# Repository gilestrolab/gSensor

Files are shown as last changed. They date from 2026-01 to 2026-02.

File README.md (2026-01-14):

# gSENSOR

An open-source high-g accelerometer project based on ESP32-C3 and ADXL375.

## Overview

gSENSOR is designed for measuring high-g accelerations (up to ±200g) with real-time display and wireless data streaming. Perfect for impact testing, vibration analysis, and other applications requiring high-g measurement.

## Features

- **High-g Measurement**: ADXL375 accelerometer with ±200g range
- **Real-time Display**: Round LCD showing live X, Y, Z values and magnitude
- **BLE Streaming**: Wireless data transmission at 20Hz to companion app
- **USB Serial Output**: 100Hz CSV data stream for logging
- **Peak Tracking**: Monitor and reset peak acceleration values
- **Android App**: Companion app for visualization, recording, and data export

## Hardware

- **MCU**: ESP32-2424S012 (ESP32-C3 with 1.28" round LCD)
- **Accelerometer**: ADXL375 (±200g, I2C interface)
- **Display**: GC9A01 round LCD (240x240)

### Wiring

| ADXL375 | ESP32-2424S012 |
|---|---|
| VCC | 3.3V |
| GND | GND |
| SDA | GPIO4 |
| SCL | GPIO5 |

## Project Structure

```
gSENSOR/
├── Firmware/           # ESP32 PlatformIO project
│   ├── src/           # Source code
│   ├── include/       # Header files
│   └── platformio.ini # Build configuration
├── gSENSOR-Android/   # Android companion app
│   ├── app/           # App source code
│   └── Dockerfile     # Docker build environment
└── 3D_Printed_Parts/  # Enclosure STL files
```

## Building

### Firmware

```bash
cd Firmware
pio run
pio run -t upload
```

### Android App

Using Docker:
```bash
cd gSENSOR-Android
docker build -t gsensor-android-build .
docker run --rm --user root -e GRADLE_USER_HOME=/tmp/gradle \
  -v "$(pwd):/app" -w /app gsensor-android-build \
  sh -c "./gradlew assembleDebug --no-daemon --project-cache-dir=/tmp/project-cache"
```

APK output: `gSENSOR-Android/app/build/outputs/apk/debug/app-debug.apk`

## BLE Protocol

**Service UUID**: `12345678-1234-5678-1234-56789abcde00`

| Characteristic | UUID | Description |
|---|---|---|
| Accel Data | `...de01` | 20-byte packet: timestamp(4) + x(4) + y(4) + z(4) + magnitude(4) |
| Peak Value | `...de02` | Peak magnitude tracking |
| Control | `...de03` | Commands: 0x01=reset peak, 0x02=reset filters |

## License

MIT License

## Author

**Giorgio Gilestro**
- Email: giorgio@gilest.ro
- GitHub: https://github.com/gilestrolab/gSensor

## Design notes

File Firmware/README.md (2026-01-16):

# gSENSOR Firmware

ESP32-based high-G accelerometer firmware for the ESP32-2424S012 development board with ADXL375 sensor.

## Features

- Real-time acceleration measurement up to **200g**
- Round LCD display with Racing HUD gauge UI
- Configurable sample rates: 100, 200, 400, 800 Hz
- BLE data streaming
- Serial data output (CSV format)
- Touch-based settings interface
- Peak value tracking with visual indicators

## Hardware

### Main Board: ESP32-2424S012

| Component | Specification |
|---|---|
| MCU | ESP32-C3-MINI-1U (4MB Flash) |
| Display | GC9A01 240x240 round LCD |
| Touch | CST816D capacitive |
| Connectivity | WiFi 802.11 b/g/n, Bluetooth 5.0 |
| Power | USB-C or 3.7V LiPo battery |

### Accelerometer: ADXL375

| Parameter | Value |
|---|---|
| Range | +/- 200g |
| Sensitivity | 49 mg/LSB |
| Interface | I2C (0x53) |
| Max Data Rate | 3200 Hz |

### Wiring

Connect the ADXL375 to the JST connector on the ESP32-2424S012:

| ADXL375 | ESP32 GPIO |
|---|---|
| VCC | 3.3V |
| GND | GND |
| SDA | GPIO21 |
| SCL | GPIO20 |

## Building & Flashing

### Prerequisites

- [PlatformIO](https://platformio.org/) (CLI or VSCode extension)

### Build

```bash
cd Firmware
pio run
```

### Flash

```bash
pio run -t upload
```

### Serial Monitor

```bash
pio device monitor
```

## Serial Interface

**Baud Rate:** 115200

### Commands

| Command | Description |
|---|---|
| `r` | Reset peak value |
| `c` | Reset filters (recalibrate) |
| `s1` | Set sample rate to 100 Hz |
| `s2` | Set sample rate to 200 Hz |
| `s3` | Set sample rate to 400 Hz |
| `s4` | Set sample rate to 800 Hz |
| `?` | Show current status |

### Output Format

CSV data is output continuously:

```
timestamp_ms,x,y,z,magnitude,peak
7257,-0.002,-0.375,-0.896,0.972,1.013
7267,-0.012,-0.380,-0.891,0.969,1.013
```

- `timestamp_ms`: Milliseconds since boot
- `x`, `y`, `z`: Acceleration in g (calibrated)
- `magnitude`: Vector magnitude sqrt(x^2 + y^2 + z^2)
- `peak`: Maximum magnitude since last reset

## Serial Plotter Tool

A Python tool for real-time visualization and data recording.

### Installation

```bash
cd tools
pip install -r requirements.txt
```

### Usage

```bash
python serial_plotter.py --port /dev/ttyACM0
```

### Controls

| Key/Button | Action |
|---|---|
| Space | Start/stop recording |
| S | Save recorded data to CSV |
| C | Clear display data |
| R | Reset peak value |

Recording automatically switches to 200 Hz for higher resolution.

## BLE Interface

### Service

- **Device Name:** gSENSOR
- **Service UUID:** `12345678-1234-5678-1234-56789abcde00`

### Characteristics

| Name | UUID | Properties |
|---|---|---|
| Accel Data | `...de01` | Notify |
| Peak | `...de02` | Notify |
| Control | `...de03` | Write |
| Config | `...de04` | Read/Write |

### Control Commands (Write to Control characteristic)

- `0x01` - Reset peak
- `0x02` - Reset filters

### Config (Write to Config characteristic)

- Byte 0: Notification rate in Hz (5-50)

## User Interface

### Main Screen (Racing HUD)

- Arc gauge showing current magnitude
- Digital readout of current value
- Peak value display
- Color-coded thresholds:
  - Green: < 10g
  - Amber: < 50g
  - Coral: < 100g
  - Red: > 100g

### Settings Screen

Tap the display to access settings:

- Toggle BLE on/off
- Toggle Serial output on/off
- Long press to return to main screen

## Configuration

Edit `src/config.h` to customize:

### Sample Rate

```cpp
constexpr uint32_t ADXL_DEFAULT_SAMPLE_RATE_HZ = 100;
```

### Calibration Offsets

Adjust for your specific ADXL375 unit:

```cpp
constexpr float ADXL375_OFFSET_X = 0.35f;
constexpr float ADXL375_OFFSET_Y = -0.60f;
constexpr float ADXL375_OFFSET_Z = 0.70f;
```

### Display Refresh Rate

```cpp
constexpr uint32_t DISPLAY_UPDATE_INTERVAL_MS = 100;  // 10 Hz
```

## Project Structure

```
Firmware/
├── src/
│   ├── main.cpp              # Entry point, main loop
│   ├── config.h              # Hardware config, constants
│   ├── accelerometer.cpp/h   # ADXL375 driver
│   ├── display.cpp/h         # GC9A01 display driver
│   ├── signal_processing.cpp/h  # Filters, magnitude calc
│   ├── ble_service.cpp/h     # BLE GATT server
│   ├── touch.cpp/h           # Touch controller
│   ├── ui_manager.cpp/h      # UI state machine
│   └── settings.h            # Runtime settings
├── tools/
│   ├── serial_plotter.py     # Python visualization tool
│   └── requirements.txt      # Python dependencies
└── platformio.ini            # Build configuration
```

## Dependencies

| Library | Version | Purpose |
|---|---|---|
| LovyanGFX | ^1.1.16 | Display driver |
| Adafruit ADXL375 | ^1.0.1 | Accelerometer driver |
| Adafruit BusIO | ^1.16.1 | I2C abstraction |
| NimBLE-Arduino | ^1.4.0 | BLE stack |

## Troubleshooting

### No serial output

1. Ensure USB CDC is enabled (check `platformio.ini` build flags)
2. Use correct port (`/dev/ttyACM0` on Linux)
3. Check baud rate is 115200

### I2C errors / No accelerometer data

1. Verify wiring to JST connector
2. Check I2C address (default 0x53)
3. Ensure 3.3V power to ADXL375

### Display not working

1. The ESP32-2424S012 uses fixed SPI pins - no configuration needed
2. Check backlight pin (GPIO3) is not conflicting

### Sample rate not changing

1. Ensure firmware is updated (serialEvent fix in v6b3c057)
2. Send command without newline: `s4` not `s4\n`

## License

MIT License - See repository root for details.

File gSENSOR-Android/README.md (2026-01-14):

# gSENSOR Android Companion App

Android companion app for the gSENSOR accelerometer device.

## Features

- **BLE Connection**: Scan and connect to gSENSOR devices via Bluetooth Low Energy
- **Real-time Display**: View live X, Y, Z acceleration and magnitude values
- **Scrolling Chart**: Visual representation of acceleration data over time
- **Peak Tracking**: Monitor and reset peak acceleration values
- **Recording**: Record acceleration sessions to local database
- **CSV Export**: Export recorded sessions to CSV format for analysis
- **Share**: Share exported data via Android share sheet

## Requirements

- Android 8.0 (API 26) or higher
- Bluetooth Low Energy support
- gSENSOR device (ESP32 + ADXL375)

## Building

### Using Docker (recommended)

```bash
docker build -t gsensor-android-build .
docker run --rm --user root -e GRADLE_USER_HOME=/tmp/gradle \
  -v "$(pwd):/app" -w /app gsensor-android-build \
  sh -c "./gradlew assembleDebug --no-daemon --project-cache-dir=/tmp/project-cache && chown -R $(id -u):$(id -g) /app/app/build"
```

The APK will be at `app/build/outputs/apk/debug/app-debug.apk`

### Using Android Studio

1. Open the project in Android Studio
2. Sync Gradle files
3. Build > Build Bundle(s) / APK(s) > Build APK(s)

## Architecture

- **Kotlin** with Jetpack Compose for UI
- **MVVM** architecture pattern
- **Room** database for local storage
- **Coroutines/Flow** for reactive data handling
- **Material3** design components

## Project Structure

```
app/src/main/java/com/gsensor/app/
├── data/
│   ├── ble/          # BLE manager and constants
│   ├── db/           # Room database
│   ├── export/       # CSV export functionality
│   ├── model/        # Data classes
│   └── repository/   # Data repository
├── ui/
│   ├── components/   # Reusable UI components
│   ├── navigation/   # Navigation graph
│   ├── screens/      # App screens
│   └── theme/        # Material theme
└── viewmodel/        # ViewModels
```

## License

MIT License

## Author

Giorgio Gilestro - giorgio@gilest.ro

## Links

- GitHub: https://github.com/gilestrolab/gSensor

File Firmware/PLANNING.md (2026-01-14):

# gSENSOR Firmware - Planning Document

## Project Overview
Firmware for an ESP32-based g-sensor device that records and displays force measurements from a laboratory shaker using an ADXL375 high-g accelerometer.

## Hardware Components

### Main Board: ESP32-2424S012
- **MCU:** ESP32-C3-MINI-1U (4MB Flash)
- **Display:** GC9A01 240x240 round LCD (SPI interface)
- **Touch:** CST816D capacitive touch (unused in this project)
- **Power:** USB-C or 360mAh 3.7V battery
- **Connectivity:** WiFi 802.11 b/g/n, Bluetooth 5.0

### Accelerometer: ADXL375 (Adafruit Breakout)
- **Range:** ±200g (fixed)
- **Sensitivity:** 49 mg/LSB
- **Interface:** I2C (address 0x53)
- **Features:** STEMMA QT/Qwiic connector

## Pin Mapping

### Display (SPI - Fixed on board)
| Function | GPIO |
|---|---|
| MOSI | 7 |
| SCLK | 6 |
| CS | 10 |
| DC | 2 |
| Backlight| 3 |

### ADXL375 I2C (via JST connector)
| JST Pin | GPIO | ADXL375 |
|---|---|---|
| GND | GND  | GND |
| 3.3V | 3.3V | VIN |
| TX | 21 | SDA |
| RX | 20 | SCL |

**Note:** ESP32-C3 only has GPIO0-21. There is no GPIO22!

## Software Architecture

### Framework
- PlatformIO with Arduino framework
- ESP32-C3 target
- LovyanGFX library for display (same as manufacturer's factory firmware)

### Module Structure
```
src/
├── main.cpp              # Application entry point
├── config.h              # Hardware configuration & calibration
├── display.h/.cpp        # GC9A01 display driver (LovyanGFX)
├── accelerometer.h/.cpp  # ADXL375 driver
└── signal_processing.h/.cpp  # Moving average filter
```

### Key Libraries
- LovyanGFX: Display driver (works reliably with ESP32-2424S012)
- Adafruit ADXL375: Accelerometer driver
- Adafruit BusIO: I2C abstraction

## Calibration

The ADXL375 has per-unit zero-g offsets that must be calibrated. Current offsets (measured with sensor flat, screen facing up):

```cpp
OFFSET_X = 0.35f   // X axis offset
OFFSET_Y = -0.60f  // Y axis offset
OFFSET_Z = 0.70f   // Z axis offset (gravity should read 1.0g)
```

To recalibrate:
1. Place sensor flat with screen facing up
2. Read raw X, Y, Z values from serial output
3. X and Y offsets = raw values (should be ~0)
4. Z offset = raw Z value - 1.0 (should be ~1.0g from gravity)

## Design Decisions

### Display Library Choice
- **LovyanGFX** used instead of TFT_eSPI
- Matches manufacturer's factory firmware configuration
- TFT_eSPI had SPI communication issues with this board

### Signal Processing
- Moving average filter with 10-sample window
- Magnitude calculated from raw data before filtering
- Peak tracking with manual reset capability

### Display Update Strategy
- Sample accelerometer at 100 Hz
- Update display at 20 Hz (50ms interval)
- Use sprite buffering to prevent flicker
- Color-coded magnitude (green < 10g, yellow < 50g, orange < 100g, red > 100g)

### I2C Configuration
- Repurpose UART pins (TX/RX) on JST connector as I2C
- GPIO21 = SDA, GPIO20 = SCL
- 400kHz I2C clock

## Serial Interface

**Baud rate:** 115200

**Important:** ESP32-C3 requires USB CDC to be enabled for serial output over USB:
```ini
build_flags =
    -DARDUINO_USB_CDC_ON_BOOT=1
    -DARDUINO_USB_MODE=1
```

**Output format (CSV):**
```
timestamp,x,y,z,magnitude,peak
7257,-0.002,-0.375,-0.896,0.972,1.013
```

**Commands:**
- `r` or `R` - Reset peak value
- `c` or `C` - Reset filters (recalibrate)

**Serial Plotter:**
A Python plotting tool is available in `tools/serial_plotter.py`:
```bash
cd tools
pip install -r requirements.txt
python serial_plotter.py --port /dev/ttyACM0
```

## Future Enhancements
- [ ] Data logging to SPIFFS
- [ ] WiFi data streaming
- [ ] Auto-calibration routine
- [ ] Configurable sample rates
- [ ] FFT analysis for vibration frequency

## References
- [ESP32-2424S012 Info](https://homeding.github.io/boards/esp32c3/jczn-esp32-2424s012.htm)
- [ADXL375 Datasheet](https://www.analog.com/media/en/technical-documentation/data-sheets/ADXL375.PDF)
- [LovyanGFX Library](https://github.com/lovyan03/LovyanGFX)
- [Manufacturer Package](http://pan.jczn1688.com/directlink/1/ESP32%20module/1.28inch_ESP32-2424S012.zip)

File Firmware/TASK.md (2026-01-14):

# gSENSOR Firmware - Task Tracking

## Completed Tasks

### 2026-01-13 - Initial Firmware Development
- [x] Create PlatformIO project structure
- [x] Configure display (switched from TFT_eSPI to LovyanGFX)
- [x] Define hardware pin configuration
- [x] Implement moving average filter
- [x] Implement ADXL375 driver with custom I2C pins
- [x] Implement display module with arc gauge
- [x] Create main application loop
- [x] Fix I2C pins (GPIO20 for SCL, not GPIO22)
- [x] Add sensor calibration offsets
- [x] Create project documentation

## Current Tasks

- [x] Create serial plotter tool

## Backlog

### Software Improvements
- [ ] Add auto-calibration routine on startup
- [ ] Add data logging to SPIFFS
- [ ] Implement WiFi streaming mode
- [ ] Add configurable sample rate via serial command
- [ ] Reduce serial debug output verbosity (add quiet mode)

### UI Enhancements
- [ ] Add min/max hold indicators
- [ ] Implement waveform view mode
- [ ] Add settings screen (touch-based)
- [ ] Improve gauge aesthetics

## Discovered During Work

- ESP32-C3 only has GPIO0-21 (no GPIO22!)
- TFT_eSPI doesn't work reliably with ESP32-2424S012; use LovyanGFX instead
- ADXL375 has significant per-unit zero-g offsets requiring calibration
- Backlight must be enabled AFTER display init (per manufacturer's code)

## Notes

### Wiring Reference
```
ESP32-2424S012 JST     Adafruit ADXL375
-------------------    -----------------
GND  ───────────────── GND
3.3V ───────────────── VIN
TX (GPIO21) ────────── SDA
RX (GPIO20) ────────── SCL
```

Note: ESP32-C3 only has GPIO0-21, there is no GPIO22!

### Calibration Values
Measured with sensor flat, screen facing up:
```cpp
OFFSET_X = 0.35f   // X reads +0.35g, should be 0
OFFSET_Y = -0.60f  // Y reads -0.6g, should be 0
OFFSET_Z = 0.70f   // Z reads +1.7g, should be +1.0g
```

### Serial Commands
- `r` or `R` - Reset peak value
- `c` or `C` - Reset filters (calibrate)

### Debug Output Format
```
RAW: X=0.00 Y=0.00 Z=1.00 | Mag=1.00 | Filtered=1.00 | Peak=1.00
```

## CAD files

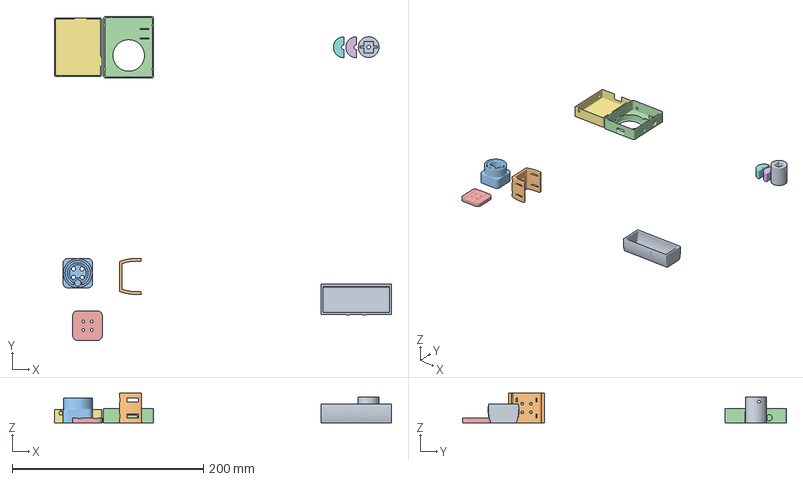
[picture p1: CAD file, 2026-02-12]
3D_Printed_Parts/gSENSOR.3mf
353.0 x 339.2 x 31.0 mm
Shaking sensor - ADXL375.stl
Vortex - Tubes Cradle.stl
Vortex - Round_Adapter.stl
LCD Case - Top.stl
Vortex - ribbon_holder.stl
Shaking sensor - Flug.stl x 2
LCD Case - Bottom.stl
Vortex - Box.stl

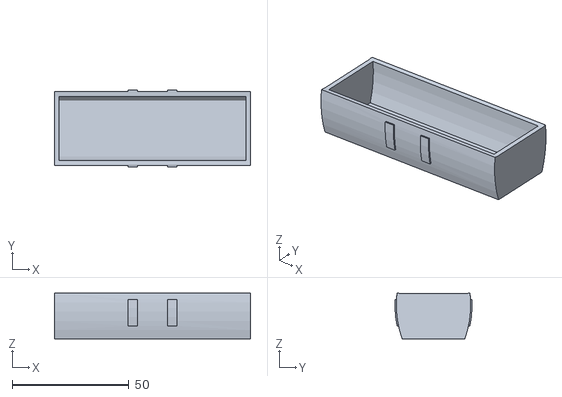
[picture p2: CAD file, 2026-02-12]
3D_Printed_Parts/Vortex/Vortex - Box.stl
84.0 x 33.0 x 19.7

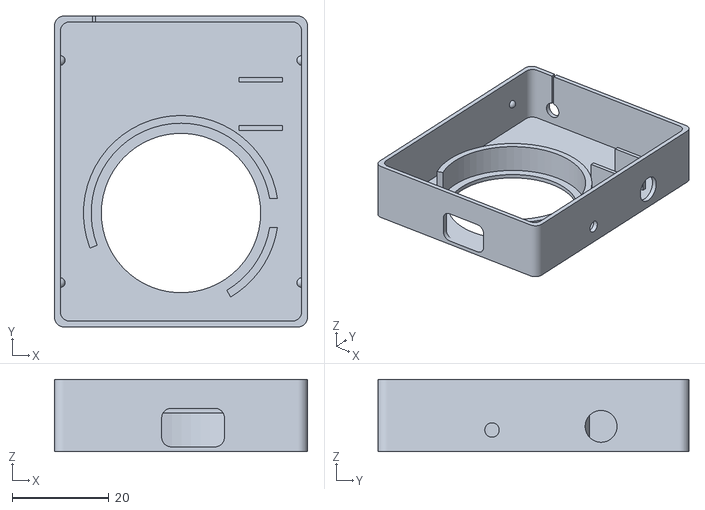
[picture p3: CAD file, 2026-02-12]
3D_Printed_Parts/LCD Case - Top.stl
52.4 x 64.4 x 15.0

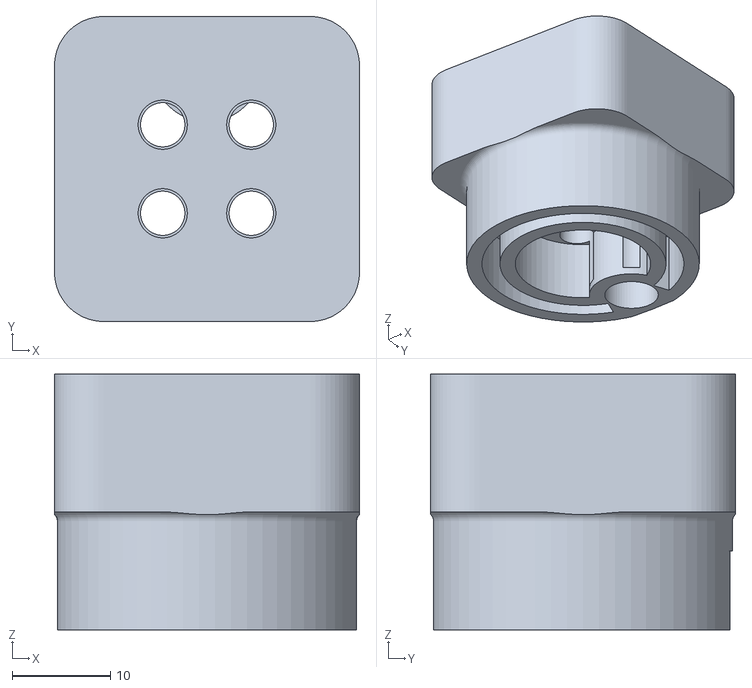
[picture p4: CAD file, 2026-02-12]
3D_Printed_Parts/Vortex/Vortex - Round_Adapter.stl
31.0 x 31.0 x 26.0

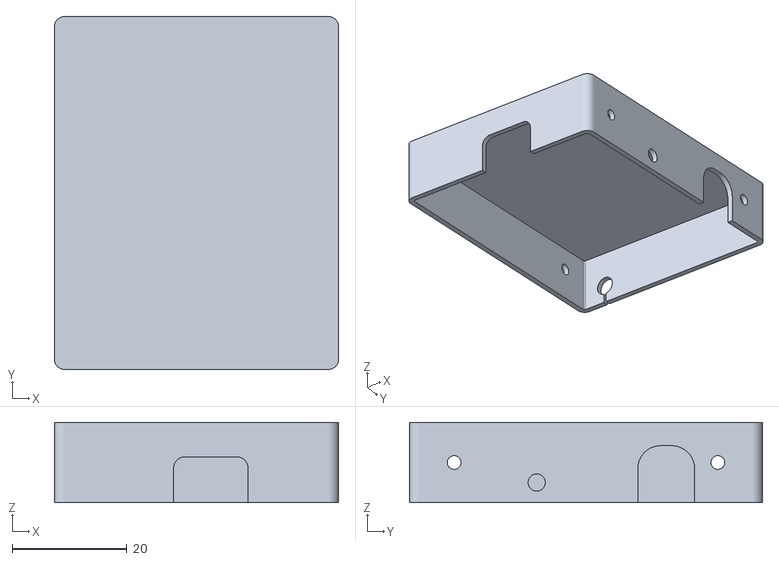
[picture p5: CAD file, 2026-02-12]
3D_Printed_Parts/LCD Case - Bottom.stl
49.6 x 61.6 x 14.0

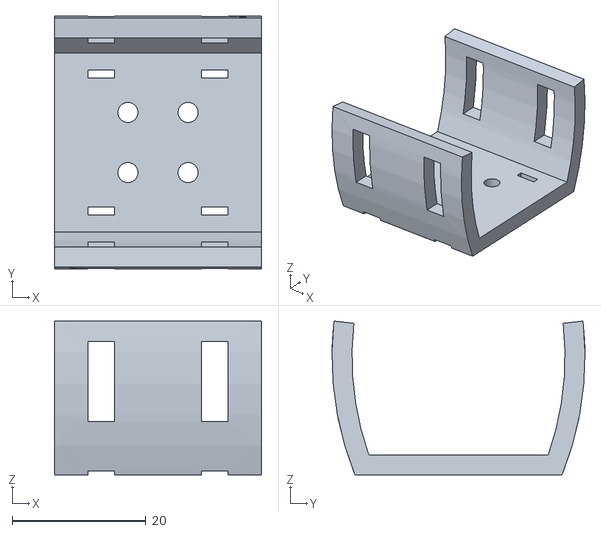
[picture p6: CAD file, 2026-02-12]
3D_Printed_Parts/Vortex/Vortex - Tubes Cradle.stl
31.0 x 37.9 x 23.0

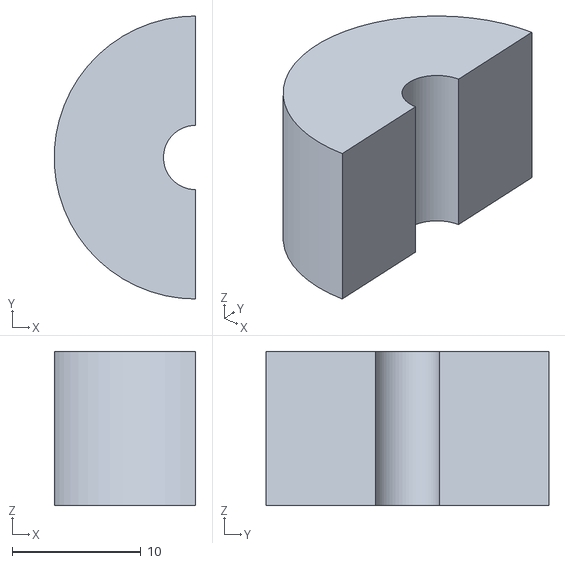
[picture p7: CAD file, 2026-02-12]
3D_Printed_Parts/Shaking sensor - Flug.stl
11.0 x 22.0 x 12.0

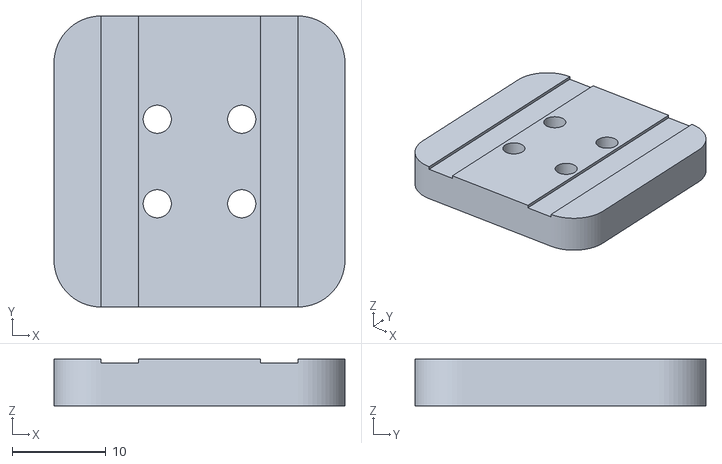
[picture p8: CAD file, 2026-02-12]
3D_Printed_Parts/Vortex/Vortex - ribbon_holder.stl
31.0 x 31.0 x 5.00

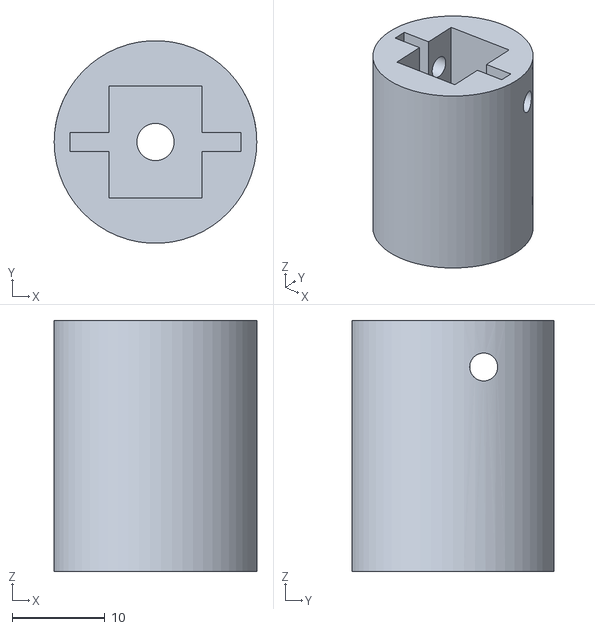
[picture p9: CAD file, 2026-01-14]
3D_Printed_Parts/Shaking sensor - ADXL375.stl
21.8 x 21.8 x 27.0

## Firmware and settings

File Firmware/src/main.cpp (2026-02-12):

/**
 * @file main.cpp
 * @brief gSENSOR main application
 *
 * Real-time g-force display using ESP32-2424S012 board with ADXL375 accelerometer.
 *
 * Hardware:
 *   - ESP32-C3 based ESP32-2424S012 board
 *   - GC9A01 240x240 round LCD display
 *   - ADXL375 high-g accelerometer (±200g) via JST connector
 *
 * Wiring (JST connector to ADXL375):
 *   - GND  -> GND
 *   - 3.3V -> VIN
 *   - TX (GPIO21) -> SDA
 *   - RX (GPIO22) -> SCL
 */

#include <Arduino.h>
#include "config.h"
#include "display.h"
#include "accelerometer.h"
#include "signal_processing.h"
#include "ble_service.h"
#include "touch.h"
#include "settings.h"
#include "ui_manager.h"

// Global objects
Display display;
Accelerometer accel;
SignalProcessor processor;
BleService bleService;
TouchManager touchMgr;
UIManager uiMgr;
Settings settings;

// Hardware timer for precise sampling
hw_timer_t* sampleTimer = nullptr;
volatile bool sampleFlag = false;

// Current sample rate (can be changed at runtime via serial command)
uint32_t currentSampleRateHz = ADXL_DEFAULT_SAMPLE_RATE_HZ;

// Timer ISR - just sets flag, actual I2C read happens in loop
void IRAM_ATTR onSampleTimer() {
    sampleFlag = true;
}

/**
 * @brief Change the accelerometer sample rate at runtime
 *
 * Updates both the hardware timer interval and the ADXL375 data rate register.
 * Valid rates: 100, 200, 400, 800 Hz (limited by serial bandwidth)
 *
 * @param rateHz Target sample rate in Hz
 * @return true if rate was changed successfully
 */
bool setSampleRate(uint32_t rateHz) {
    // Map Hz to ADXL data rate enum
    adxl3xx_dataRate_t adxlRate;
    switch (rateHz) {
        case 100:  adxlRate = ADXL3XX_DATARATE_100_HZ; break;
        case 200:  adxlRate = ADXL3XX_DATARATE_200_HZ; break;
        case 400:  adxlRate = ADXL3XX_DATARATE_400_HZ; break;
        case 800:  adxlRate = ADXL3XX_DATARATE_800_HZ; break;
        default:
            Serial.printf("Invalid rate: %d Hz\n", rateHz);
            return false;
    }

    // Update ADXL375 data rate
    accel.setDataRate(adxlRate);

    // Calculate new timer interval in microseconds
    uint32_t intervalUs = 1000000 / rateHz;

    // Update hardware timer
    timerAlarmDisable(sampleTimer);
    timerAlarmWrite(sampleTimer, intervalUs, true);
    timerAlarmEnable(sampleTimer);

    currentSampleRateHz = rateHz;
    Serial.printf("Sample rate: %d Hz\n", rateHz);
    return true;
}

// Timing variables
uint32_t lastDisplayTime = 0;
uint32_t lastBLENotifyTime = 0;

// State
bool sensorOk = false;

// Forward declaration (ESP32 doesn't auto-call serialEvent like classic Arduino)
void serialEvent();

/**
 * @brief Arduino setup function
 */
void setup() {
    // Initialize serial for debugging
    Serial.begin(SERIAL_BAUD_RATE);
    delay(500);  // Give serial more time to initialize

    Serial.println();
    Serial.println("================================");
    Serial.println("  gSENSOR - High-G Accelerometer");
    Serial.println("================================");
    Serial.println();
    Serial.println("[Setup] Starting...");

    // Initialize display first (shows splash screen)
    Serial.println("[Setup] Initializing display...");
    if (!display.begin()) {
        Serial.println("ERROR: Display initialization failed!");
        while (1) {
            delay(500);
        }
    }
    Serial.println("[Setup] Display OK, showing splash...");

    display.showSplash();
    Serial.println("[Setup] Splash shown, waiting...");
    delay(1500);  // Show splash for 1.5 seconds

    // Initialize accelerometer
    Serial.println("[Setup] Initializing ADXL375...");
    sensorOk = accel.begin();

    if (!sensorOk) {
        display.showError("ADXL375 NOT FOUND");
        Serial.println("ERROR: Accelerometer initialization failed!");
        Serial.println("Check wiring:");
        Serial.println("  JST GND  -> ADXL375 GND");
        Serial.println("  JST 3.3V -> ADXL375 VIN");
        Serial.println("  JST TX   -> ADXL375 SDA");
        Serial.println("  JST RX   -> ADXL375 SCL");
        // Continue anyway to show error on display
    } else {
        Serial.println("[Setup] ADXL375 OK, drawing UI...");
        // Clear display and draw static UI
        display.clear();
        display.drawStaticUI();
        Serial.println("[Setup] UI drawn");
    }

    // Initialize touch controller
    Serial.println("[Setup] Initializing touch...");
    if (touchMgr.begin()) {
        Serial.println("[Setup] Touch controller OK");
    } else {
        Serial.println("WARNING: Touch controller not found");
    }

    // Initialize BLE
    Serial.println("[Setup] Initializing BLE...");
    bleService.begin();
    Serial.println("[Setup] BLE OK");

    // Register BLE command callback
    bleService.setCommandCallback([](uint8_t cmd) {
        switch (cmd) {
            case BLE_CMD_RESET_PEAK:
                processor.resetPeak();
                display.resetGaugeMax();
                if (DEBUG_ENABLED) {
                    Serial.println("BLE: Peak reset");
                }
                break;

            case BLE_CMD_RESET_FILTERS:
                processor.reset();
                if (DEBUG_ENABLED) {
                    Serial.println("BLE: Filters reset");
                }
                break;

            case BLE_CMD_SET_SAMPLE_RATE_100HZ:
                if (setSampleRate(ADXL_RATE_100HZ)) {
                    settings.sampleRateHz = ADXL_RATE_100HZ;
                    if (DEBUG_ENABLED) {
                        Serial.println("BLE: Sample rate set to 100 Hz");
                    }
                }
                break;

            case BLE_CMD_SET_SAMPLE_RATE_200HZ:
                if (setSampleRate(ADXL_RATE_200HZ)) {
                    settings.sampleRateHz = ADXL_RATE_200HZ;
                    if (DEBUG_ENABLED) {
                        Serial.println("BLE: Sample rate set to 200 Hz");
                    }
                }
                break;

            case BLE_CMD_SET_SAMPLE_RATE_400HZ:
                if (setSampleRate(ADXL_RATE_400HZ)) {
                    settings.sampleRateHz = ADXL_RATE_400HZ;
                    if (DEBUG_ENABLED) {
                        Serial.println("BLE: Sample rate set to 400 Hz");
                    }
                }
                break;

            default:
                if (DEBUG_ENABLED) {
                    Serial.print("BLE: Unknown command 0x");
                    Serial.println(cmd, HEX);
                }
                break;
        }
    });

    // Initialize physical button
    pinMode(PIN_BUTTON, INPUT_PULLUP);
    Serial.println("[Setup] Button initialized on GPIO9");

    // Set up hardware timer for sampling
    // Timer 0, prescaler 80 (80MHz/80 = 1MHz tick rate), count up
    sampleTimer = timerBegin(0, 80, true);
    timerAttachInterrupt(sampleTimer, &onSampleTimer, true);
    // Set initial rate (can be changed at runtime via serial command s1-s4)
    uint32_t initialIntervalUs = 1000000 / ADXL_DEFAULT_SAMPLE_RATE_HZ;
    timerAlarmWrite(sampleTimer, initialIntervalUs, true);
    timerAlarmEnable(sampleTimer);
    Serial.printf("[Setup] Sample timer configured for %d Hz (s1-s4 to change)\n", ADXL_DEFAULT_SAMPLE_RATE_HZ);

    // Initialize timing
    lastDisplayTime = millis();
    lastBLENotifyTime = millis();

    Serial.println("[Setup] Complete! Entering main loop...");
}

/**
 * @brief Arduino main loop
 */
void loop() {
    // Sample accelerometer FIRST when timer fires (highest priority!)
    // The timer ISR sets sampleFlag at precise 100Hz intervals
    if (sampleFlag && sensorOk) {
        sampleFlag = false;  // Clear flag immediately

        AccelData raw;
        if (accel.read(raw)) {
            // Process through moving average filter
            AccelData filtered = processor.process(raw);

            // Serial output in CSV format for plotting (if enabled)
            // Format: timestamp,x,y,z,magnitude,peak
            if (DEBUG_ENABLED && settings.serialEnabled) {
                float mag = processor.getFilteredMagnitude();
                float peak = processor.getPeakMagnitude();

                Serial.print(millis());
                Serial.print(",");
                Serial.print(filtered.x, 3);
                Serial.print(",");
                Serial.print(filtered.y, 3);
                Serial.print(",");
                Serial.print(filtered.z, 3);
                Serial.print(",");
                Serial.print(mag, 3);
                Serial.print(",");
                Serial.println(peak, 3);
            }
        }
    }

    uint32_t now = millis();

    // Handle physical button (active LOW, debounced)
    static bool lastButtonState = HIGH;
    static uint32_t lastButtonTime = 0;
    bool buttonState = digitalRead(PIN_BUTTON);

    if (buttonState != lastButtonState && (now - lastButtonTime) > 200) {
        lastButtonTime = now;
        if (buttonState == LOW) {
            // Button pressed - toggle screen
            if (uiMgr.getScreen() == UIScreen::MAIN_GAUGE) {
                uiMgr.setScreen(UIScreen::SETTINGS);
                Serial.println("[Button] Opening settings");
            } else {
                uiMgr.setScreen(UIScreen::MAIN_GAUGE);
                Serial.println("[Button] Back to gauge");
            }
        }
        lastButtonState = buttonState;
    }

    // Handle touch input (skipped if no touch controller)
    touchMgr.update();
    TouchEvent event = touchMgr.getEvent();
    if (event.gesture != TouchGesture::NONE) {
        uiMgr.handleTouch(event, settings);

        // Handle BLE enable/disable from settings
        bleService.setEnabled(settings.bleEnabled);
    }

    // Handle peak reset from UI (long press)
    if (uiMgr.peakResetRequested()) {
        processor.resetPeak();
        display.resetGaugeMax();
        if (DEBUG_ENABLED && settings.serialEnabled) {
            Serial.println("Peak reset (touch)");
        }
    }

    // Update display at lower rate (to prevent flicker and save CPU)
    if (now - lastDisplayTime >= DISPLAY_UPDATE_INTERVAL_MS) {
        lastDisplayTime = now;

        // Check if screen changed (need to prepare)
        if (uiMgr.screenChanged()) {
            display.prepareScreen();
        }

        // Draw appropriate screen
        if (uiMgr.getScreen() == UIScreen::MAIN_GAUGE) {
            AccelData accelData = {0, 0, 0};
            float magnitude = 0.0f;
            float peak = 0.0f;

            if (sensorOk) {
                accelData = processor.getLastFiltered();
                magnitude = processor.getFilteredMagnitude();
                peak = processor.getPeakMagnitude();
            }

            display.update(accelData, magnitude, peak);
        } else {
            // Settings screen
            display.drawSettingsScreen(settings, bleService.isConnected());
        }
    }

    // Send BLE notifications at configured rate (if BLE is enabled)
    if (settings.bleEnabled && bleService.isConnected() && sensorOk) {
        uint32_t bleInterval = 1000 / bleService.getNotificationRate();
        if (now - lastBLENotifyTime >= bleInterval) {
            lastBLENotifyTime = now;

            const AccelData& filtered = processor.getLastFiltered();
            float magnitude = processor.getFilteredMagnitude();
            float peak = processor.getPeakMagnitude();

            bleService.notifyAccelData(now, filtered, magnitude);

            // Also send peak update periodically (every ~500ms)
            static uint32_t lastPeakNotify = 0;
            if (now - lastPeakNotify >= 500) {
                lastPeakNotify = now;
                bleService.notifyPeak(now, peak);
            }
        }
    }

    // Handle serial commands (ESP32 doesn't auto-call serialEvent)
    serialEvent();

    // Small delay to prevent tight loop (saves power)
    delay(1);
}

/**
 * @brief Handle serial commands
 *
 * Commands:
 *   'r' - Reset peak value
 *   'c' - Calibrate (reset filters)
 *   's1' - Set sample rate to 100 Hz
 *   's2' - Set sample rate to 200 Hz
 *   's3' - Set sample rate to 400 Hz
 *   's4' - Set sample rate to 800 Hz
 *   '?' - Print current status
 */
void serialEvent() {
    static bool expectingRateDigit = false;

    while (Serial.available()) {
        char cmd = Serial.read();

        // Handle rate digit after 's' command
        if (expectingRateDigit) {
            expectingRateDigit = false;
            switch (cmd) {
                case '1': setSampleRate(ADXL_RATE_100HZ); break;
                case '2': setSampleRate(ADXL_RATE_200HZ); break;
                case '3': setSampleRate(ADXL_RATE_400HZ); break;
                case '4': setSampleRate(ADXL_RATE_800HZ); break;
                default:
                    Serial.println("Invalid rate. Use s1=100Hz, s2=200Hz, s3=400Hz, s4=800Hz");
                    break;
            }
            continue;
        }

        switch (cmd) {
            case 'r':
            case 'R':
                processor.resetPeak();
                display.resetGaugeMax();
                if (DEBUG_ENABLED && settings.serialEnabled) {
                    Serial.println("Peak reset");
                }
                break;

            case 'c':
            case 'C':
                processor.reset();
                if (DEBUG_ENABLED && settings.serialEnabled) {
                    Serial.println("Filters reset");
                }
                break;

            case 's':
            case 'S':
                expectingRateDigit = true;
                break;

            case '?':
                Serial.printf("Rate: %d Hz | Commands: r=reset peak, c=calibrate, s1-s4=rate, ?=status\n",
                              currentSampleRateHz);
                break;

            default:
                break;
        }
    }
}

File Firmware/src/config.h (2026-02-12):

/**
 * @file config.h
 * @brief Hardware configuration and constants for gSENSOR
 *
 * Pin definitions for ESP32-2424S012 board with ADXL375 accelerometer.
 */

#ifndef CONFIG_H
#define CONFIG_H

#include <Arduino.h>

// ==================== Board Information ====================
// ESP32-2424S012 uses ESP32-C3-MINI-1U module
// - 4MB Flash
// - USB-C for programming and power
// - 240x240 GC9A01 round display
// - CST816D touch controller (unused in this project)

// ==================== Display Pins (SPI - Fixed) ====================
// These are defined in User_Setup.h for TFT_eSPI
// Listed here for reference only
constexpr uint8_t PIN_TFT_MOSI = 7;
constexpr uint8_t PIN_TFT_SCLK = 6;
constexpr uint8_t PIN_TFT_CS   = 10;
constexpr uint8_t PIN_TFT_DC   = 2;
constexpr uint8_t PIN_TFT_BL   = 3;

// ==================== Touch Controller Pins (CST816D) ====================
// Internal I2C bus (separate from ADXL375)
constexpr uint8_t PIN_TOUCH_SDA = 4;
constexpr uint8_t PIN_TOUCH_SCL = 5;
constexpr uint8_t PIN_TOUCH_INT = 0;
constexpr uint8_t PIN_TOUCH_RST = 1;
constexpr uint8_t TOUCH_I2C_ADDR = 0x15;

// ==================== ADXL375 I2C Pins (JST Connector) ====================
// The JST connector exposes UART pins which we repurpose for I2C
// JST Pinout: GND, 3.3V, TX (GPIO21), RX (GPIO20)
// Note: ESP32-C3 only has GPIO0-21, there is no GPIO22!
constexpr uint8_t PIN_ADXL_SDA = 21;  // JST TX pin -> I2C SDA
constexpr uint8_t PIN_ADXL_SCL = 20;  // JST RX pin -> I2C SCL

// ADXL375 I2C address (ALT ADDRESS pin LOW on Adafruit board)
constexpr uint8_t ADXL375_I2C_ADDR = 0x53;

// Calibration offsets (measured with sensor flat, screen up)
// These values are subtracted from raw readings
// Adjust these based on your sensor's readings at rest
constexpr float OFFSET_X = 0.35f;   // X reads +0.35g when should be 0
constexpr float OFFSET_Y = -0.60f;  // Y reads -0.6g when should be 0
constexpr float OFFSET_Z = 0.70f;   // Z reads +1.7g when should be +1.0g (gravity)

// ==================== Display Configuration ====================
constexpr uint16_t DISPLAY_WIDTH  = 240;
constexpr uint16_t DISPLAY_HEIGHT = 240;
constexpr uint16_t DISPLAY_CENTER_X = DISPLAY_WIDTH / 2;
constexpr uint16_t DISPLAY_CENTER_Y = DISPLAY_HEIGHT / 2;

// Display refresh rate (milliseconds)
constexpr uint32_t DISPLAY_UPDATE_INTERVAL_MS = 100;  // 10 Hz refresh (slower for consistent sampling)

// ==================== ADXL375 Configuration ====================
// Fixed range: +/- 200g
// Sensitivity: 49 mg/LSB (0.049 g per LSB)
constexpr float ADXL375_SCALE_FACTOR = 0.049f;  // g per LSB
constexpr float ADXL375_MAX_G = 200.0f;

// Sample rate (Hz) - ADXL375 can output up to 3200 Hz
// Default rate for display, can be changed at runtime via serial command
constexpr uint32_t ADXL_DEFAULT_SAMPLE_RATE_HZ = 100;

// Available sample rates (serial command: s1-s4)
// Limited to 800 Hz max due to serial bandwidth at 115200 baud
constexpr uint32_t ADXL_RATE_100HZ  = 100;   // s1 - default/low power
constexpr uint32_t ADXL_RATE_200HZ  = 200;   // s2
constexpr uint32_t ADXL_RATE_400HZ  = 400;   // s3
constexpr uint32_t ADXL_RATE_800HZ  = 800;   // s4 - max for serial

// ==================== Signal Processing ====================
// Moving average filter window size
// Larger = smoother but more latency
// At 100 Hz sample rate:
//   10 samples = 100ms averaging window
//   20 samples = 200ms averaging window
constexpr size_t MOVING_AVG_WINDOW_SIZE = 10;

// ==================== UI Configuration ====================
// Pastel/neutral color palette (RGB565 format)
constexpr uint16_t UI_BG_PRIMARY     = 0x0000;   // Pure black background
constexpr uint16_t UI_BG_SECONDARY   = 0x18E3;   // Dark gray (25, 28, 30)
constexpr uint16_t UI_TEXT_PRIMARY   = 0xF7BE;   // Cream/warm white (245, 240, 240)
constexpr uint16_t UI_TEXT_SECONDARY = 0xAD55;   // Warm gray (170, 170, 170)
constexpr uint16_t UI_TEXT_MUTED     = 0x52AA;   // Muted gray (80, 85, 85)
constexpr uint16_t UI_ACCENT         = 0xAE9A;   // Soft coral/peach (172, 210, 210)
constexpr uint16_t UI_GAUGE_BG       = 0x2104;   // Dark gauge background (32, 32, 32)

// G-force pastel colors
constexpr uint16_t COLOR_LOW_G      = 0x9F93;   // Soft sage green (158, 248, 155)
constexpr uint16_t COLOR_MED_G      = 0xFED3;   // Soft peach/amber (255, 218, 155)
constexpr uint16_t COLOR_HIGH_G     = 0xFBCE;   // Soft coral (250, 188, 115)
constexpr uint16_t COLOR_EXTREME_G  = 0xFB2C;   // Soft red/salmon (250, 100, 100)

// ==================== Button Configuration ====================
constexpr uint8_t PIN_BUTTON = 9;  // Boot button on ESP32-C3 (active LOW)

// G-force thresholds for color changes
constexpr float G_THRESHOLD_LOW     = 10.0f;
constexpr float G_THRESHOLD_MED     = 50.0f;
constexpr float G_THRESHOLD_HIGH    = 100.0f;
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

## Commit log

2026-01-14 Initial release: gSENSOR accelerometer project
    Complete open-source high-g accelerometer project based on ESP32-C3 and ADXL375.
    ## Firmware (ESP32)
    - ADXL375 accelerometer driver (I2C, ±200g range)
    - Real-time round LCD display (GC9A01)
    - BLE GATT server for wireless streaming (20Hz)
    - USB CDC serial output (100Hz CSV)
    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
    [LCD CASE - Round_LCD_Case_TOP.3mf, LCD Case - Round_LCD_Case_TOP.stl, Shaking sensor - ADXL375.stl]
2026-01-14 Add Racing HUD UI, touch support, settings screen, and timer-based sampling
    UI Improvements:
    - Racing HUD style with segmented arc gauge
    - Smooth anti-aliased fonts (FreeSans family via LovyanGFX)
    - Pastel/neutral color palette with cream text
    - Framed Peak display box with rounded corners
    - Dynamic gauge range (0-10g default, adapts to 20/50/100/200g)
    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
2026-01-14 Add configurable sample rate and improved serial plotter GUI
    Firmware:
    - Add runtime-configurable sample rate (100/200/400/800 Hz)
    - Add serial commands: s1-s4 for rate, ? for status
    - Fix serialEvent() not being called on ESP32 (add explicit call in loop)
    - Add setSampleRate() function to update timer and ADXL375 dynamically
    Serial Plotter:
    - Add GUI buttons: Record, Save CSV, Clear, Reset Peak
    - Add keyboard shortcuts: Space, S, C, R
    - Auto-switch to high sample rate when recording starts
    - Add CSV export with metadata header
    - Add error handling for serial disconnects
    - Default recording rate: 200 Hz (safe for 115200 baud)
    [config.h, main.cpp, serial_plotter.py]
2026-02-12 Add BLE sample rate control (100/200/400 Hz)
    Allow the Android app to remotely change the sensor acquisition rate
    via BLE commands. Adds a settings bottom sheet in the live screen with
    radio button selection and an info card explaining BLE streaming limits.
2026-02-12 Update 3D printed parts with new case and vortex designs
    Replace old round LCD case with separate top/bottom parts, add shaking
    sensor plug, vortex adapter parts, and consolidated 3MF project file.
    [LCD CASE - Round_LCD_Case_TOP.3mf, LCD Case - Bottom.stl, LCD Case - Round_LCD_Case_TOP.stl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]
